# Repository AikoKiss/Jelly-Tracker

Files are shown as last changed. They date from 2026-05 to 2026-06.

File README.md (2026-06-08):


# Puchi Tracker
A smol-slime style tracker, with only the top-end parts, double-sided, NRF54L10 with ICM45686+QMC6309. Battery life is to be tested.

Thank you to Crylog for being an Absolute chad and unit of a PCB designer.
+ Mumo Tracker for the nice footprints and 3D files, making it easier to design the PCB.
+ Thank you, the slime community, for bullying all the bugs out of my design.
+ Special thanks to Meia for taking the time to help me squash all my stupid decisions and bugs.

## License

This project is source-available for personal and
educational use only.

Commercial use, manufacturing, resale, or distribution
For-profit is prohibited without written permission
from Limeneer Labs.

See the [LICENSE](LICENSE) file for full details.

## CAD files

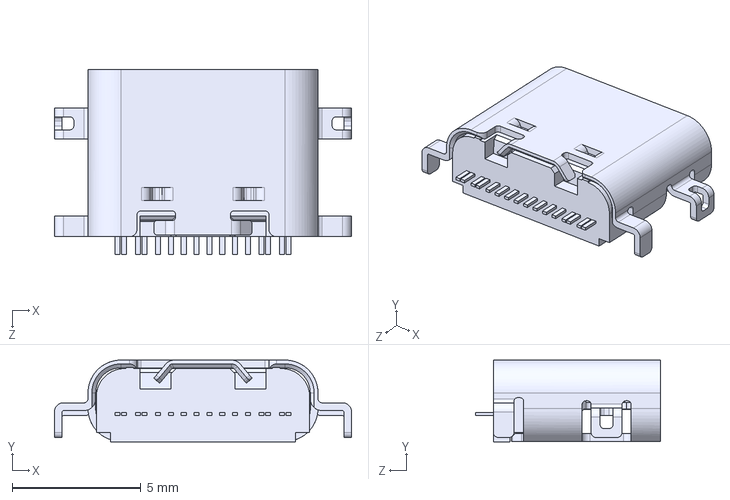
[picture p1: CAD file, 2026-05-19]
PuchiTrackerV6/GSB1C4621DS1HR/GSB1C4621DS1HR.step
11.5 x 3.18 x 7.20 mm

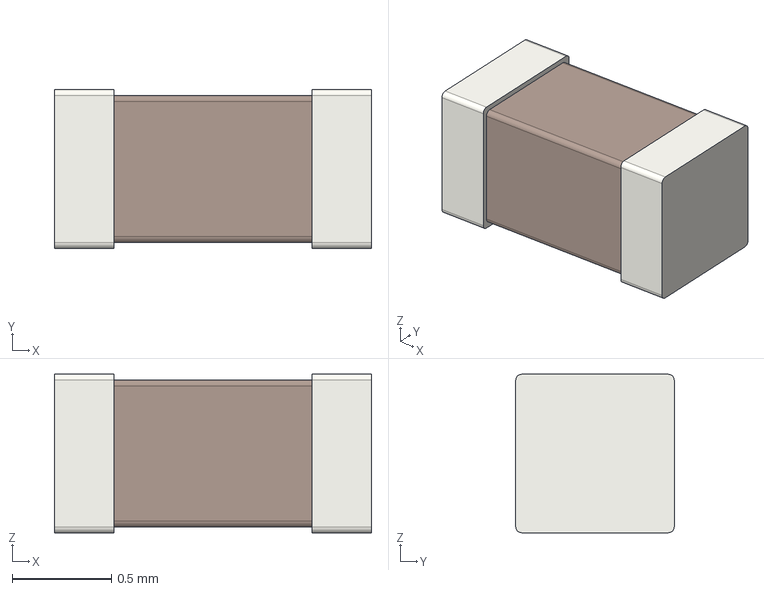
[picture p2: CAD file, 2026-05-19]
PuchiTrackerV6/Mumo Data/Mumo Models/C_0603_1608Metric.step
1.60 x 0.8 x 0.8 mm

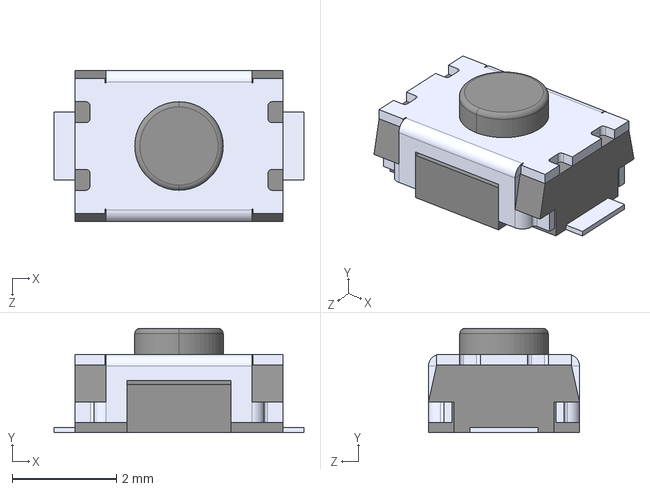
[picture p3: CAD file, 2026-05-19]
PuchiTrackerV6/TS-1088-AR02016/TS-1088-AR02016.step
4.80 x 2.00 x 2.90 mm

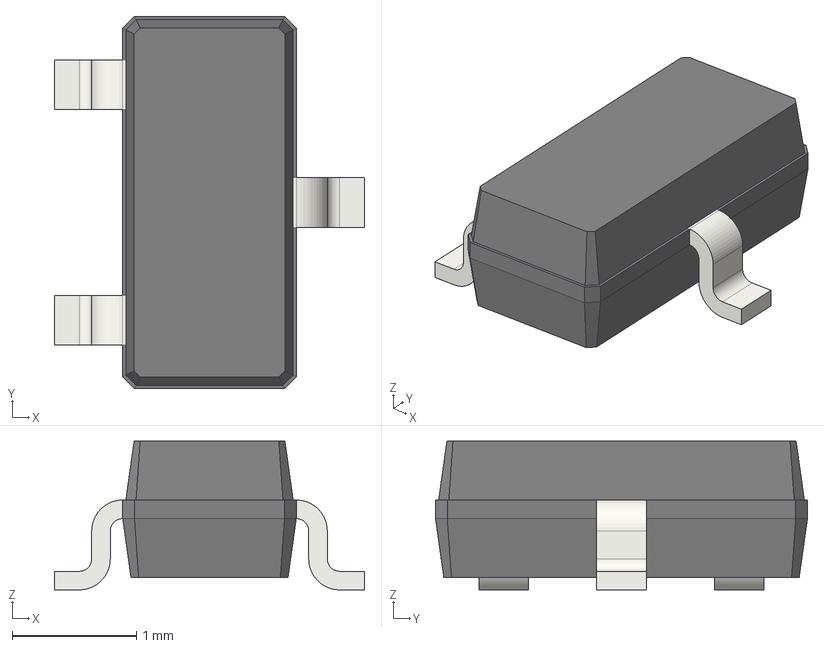
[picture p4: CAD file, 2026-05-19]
PuchiTrackerV6/Mumo Data/Mumo Models/SOT-23.step
2.50 x 3.00 x 1.20 mm

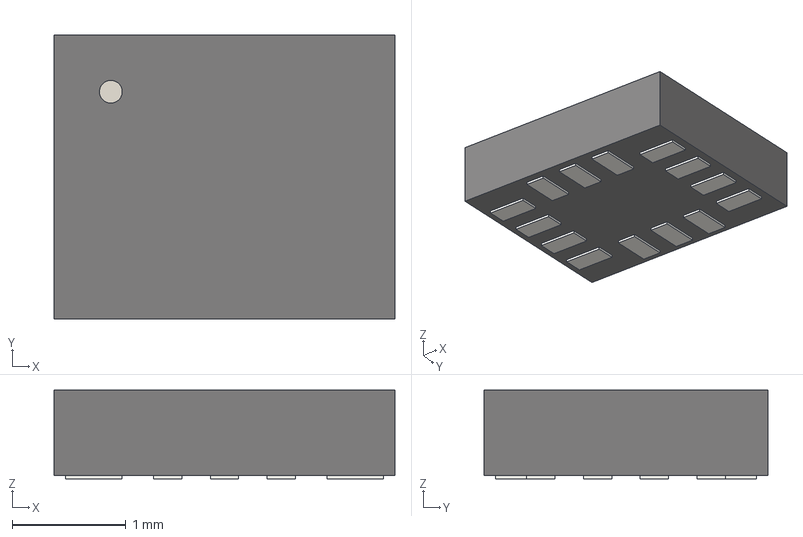
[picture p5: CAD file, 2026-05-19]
PuchiTrackerV6/Mumo Data/Mumo Models/Bosch_LGA-14_3x2.5mm_P0.5mm.step
3.00 x 2.50 x 0.78 mm

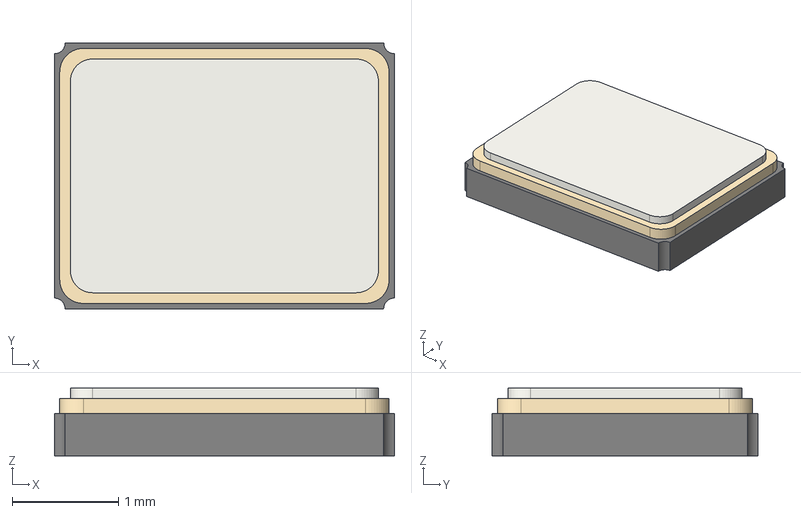
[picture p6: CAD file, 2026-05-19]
PuchiTrackerV6/Mumo Data/Mumo Models/Crystal_SMD_3225-4Pin_3.2x2.5mm.step
3.20 x 2.50 x 0.64 mm

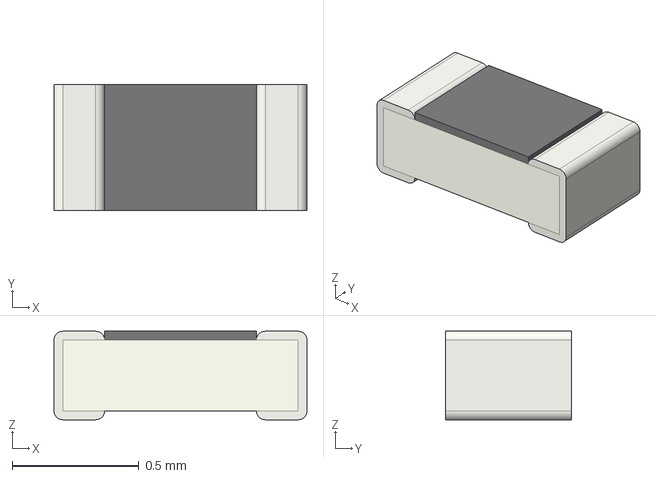
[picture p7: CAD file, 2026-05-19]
PuchiTrackerV6/Mumo Data/Mumo Models/R_0402_1005Metric.step
1.00 x 0.5 x 0.35 mm

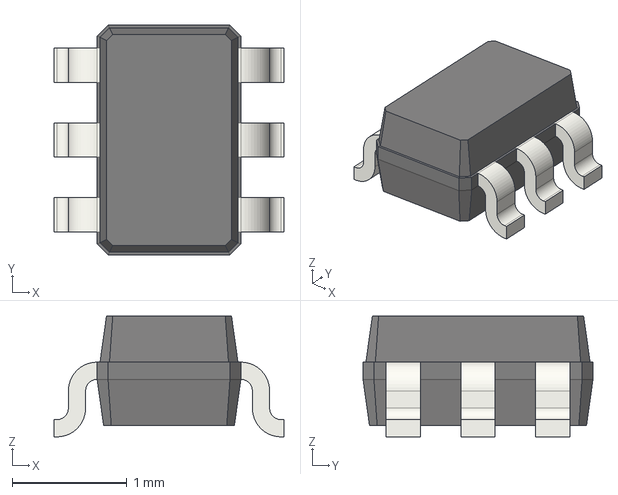
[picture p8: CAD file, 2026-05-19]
PuchiTrackerV6/Mumo Data/Mumo Models/SOT-363_SC-70-6.step
2.00 x 2.00 x 1.05 mm

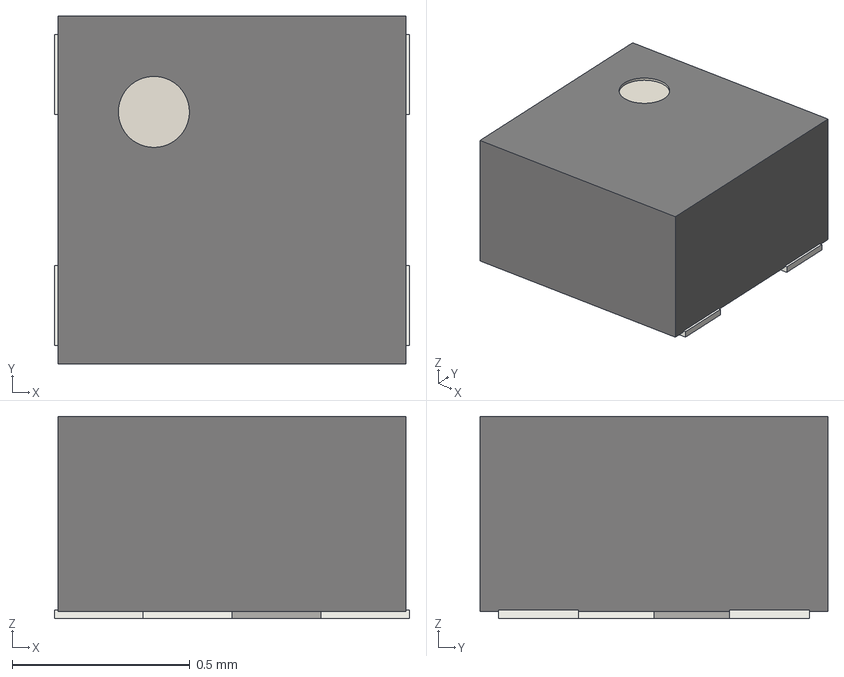
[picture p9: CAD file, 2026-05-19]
PuchiTrackerV6/Mumo Data/Mumo Models/UDFN-4-1EP_1x1mm_P0.65mm_EP0.48x0.48mm.step
1.00 x 0.98 x 0.57 mm

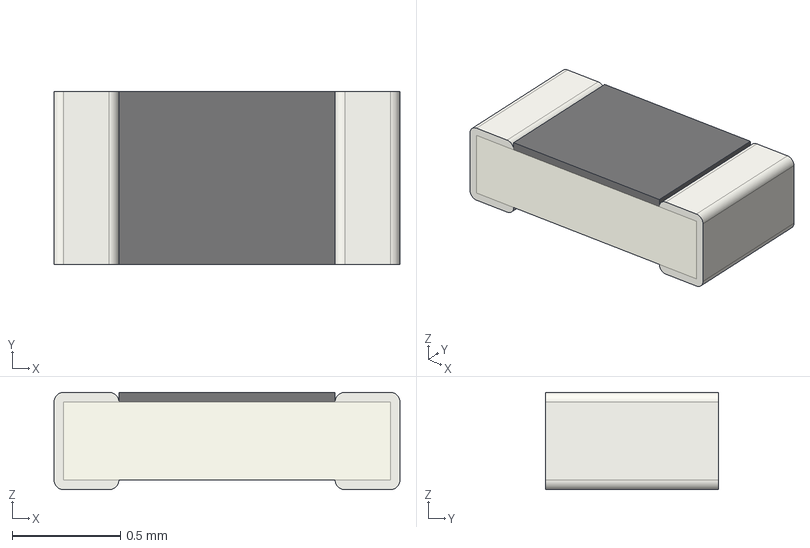
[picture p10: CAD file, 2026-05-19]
PuchiTrackerV6/Mumo Data/Mumo Models/R_0603_1608Metric.step
1.60 x 0.8 x 0.45 mm

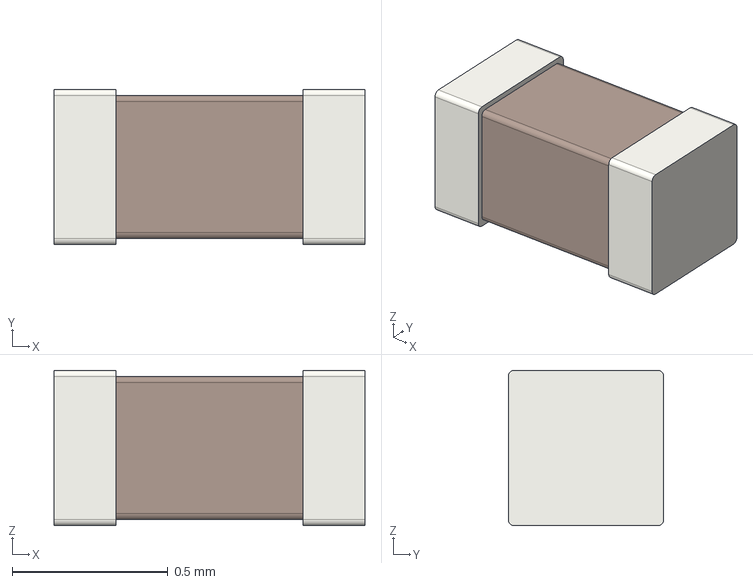
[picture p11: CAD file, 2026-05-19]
PuchiTrackerV6/Mumo Data/Mumo Models/C_0402_1005Metric.step
1.00 x 0.5 x 0.5 mm

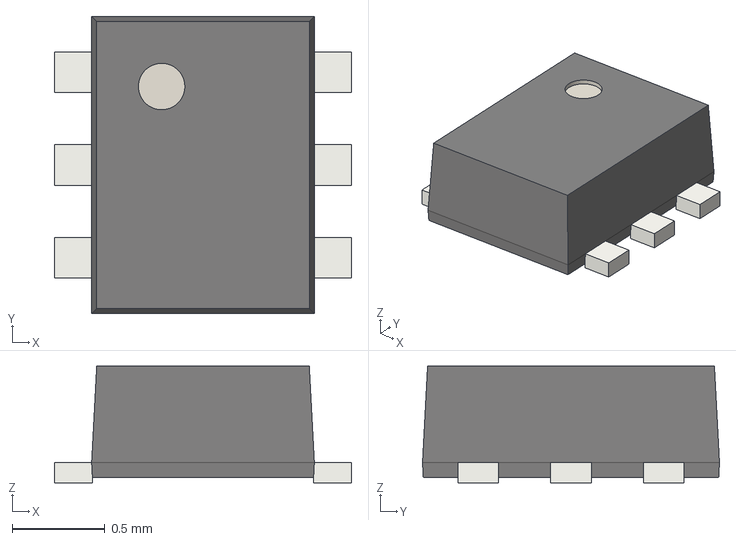
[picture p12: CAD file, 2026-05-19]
PuchiTrackerV6/Mumo Data/Mumo Models/SOT-563.step
1.60 x 1.60 x 0.63 mm

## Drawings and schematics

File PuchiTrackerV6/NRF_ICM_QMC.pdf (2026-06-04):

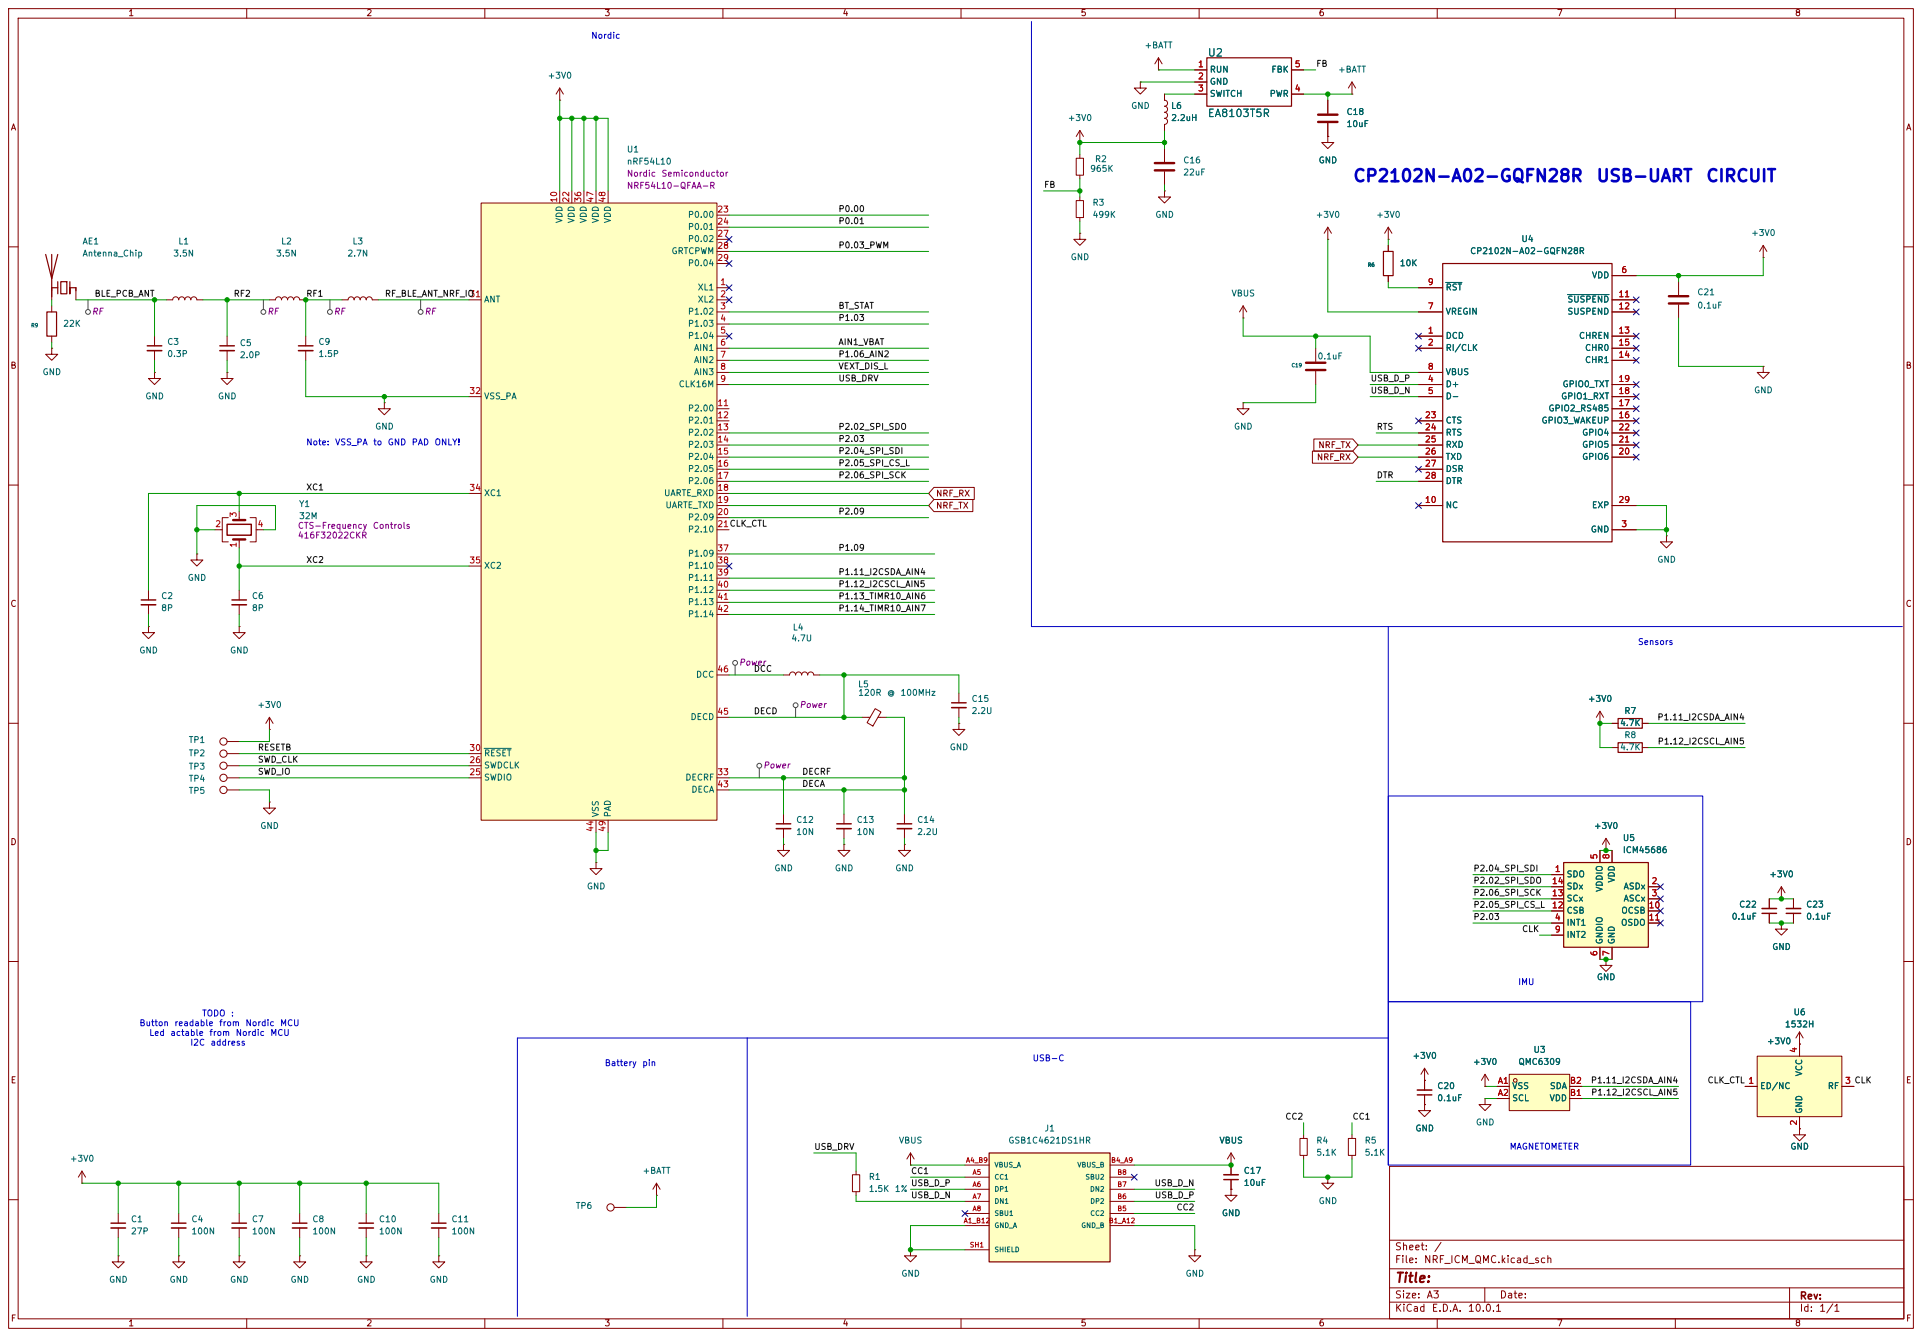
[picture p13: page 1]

IMU | ICM45686 GND +3V0 R5

TODO : Button readable from Nordic MCU

Led actable from Nordic MCU

GND

Size: A3 | Rev: | F Date:
KiCad E.D.A. 10.0.1 | Id: 1/1

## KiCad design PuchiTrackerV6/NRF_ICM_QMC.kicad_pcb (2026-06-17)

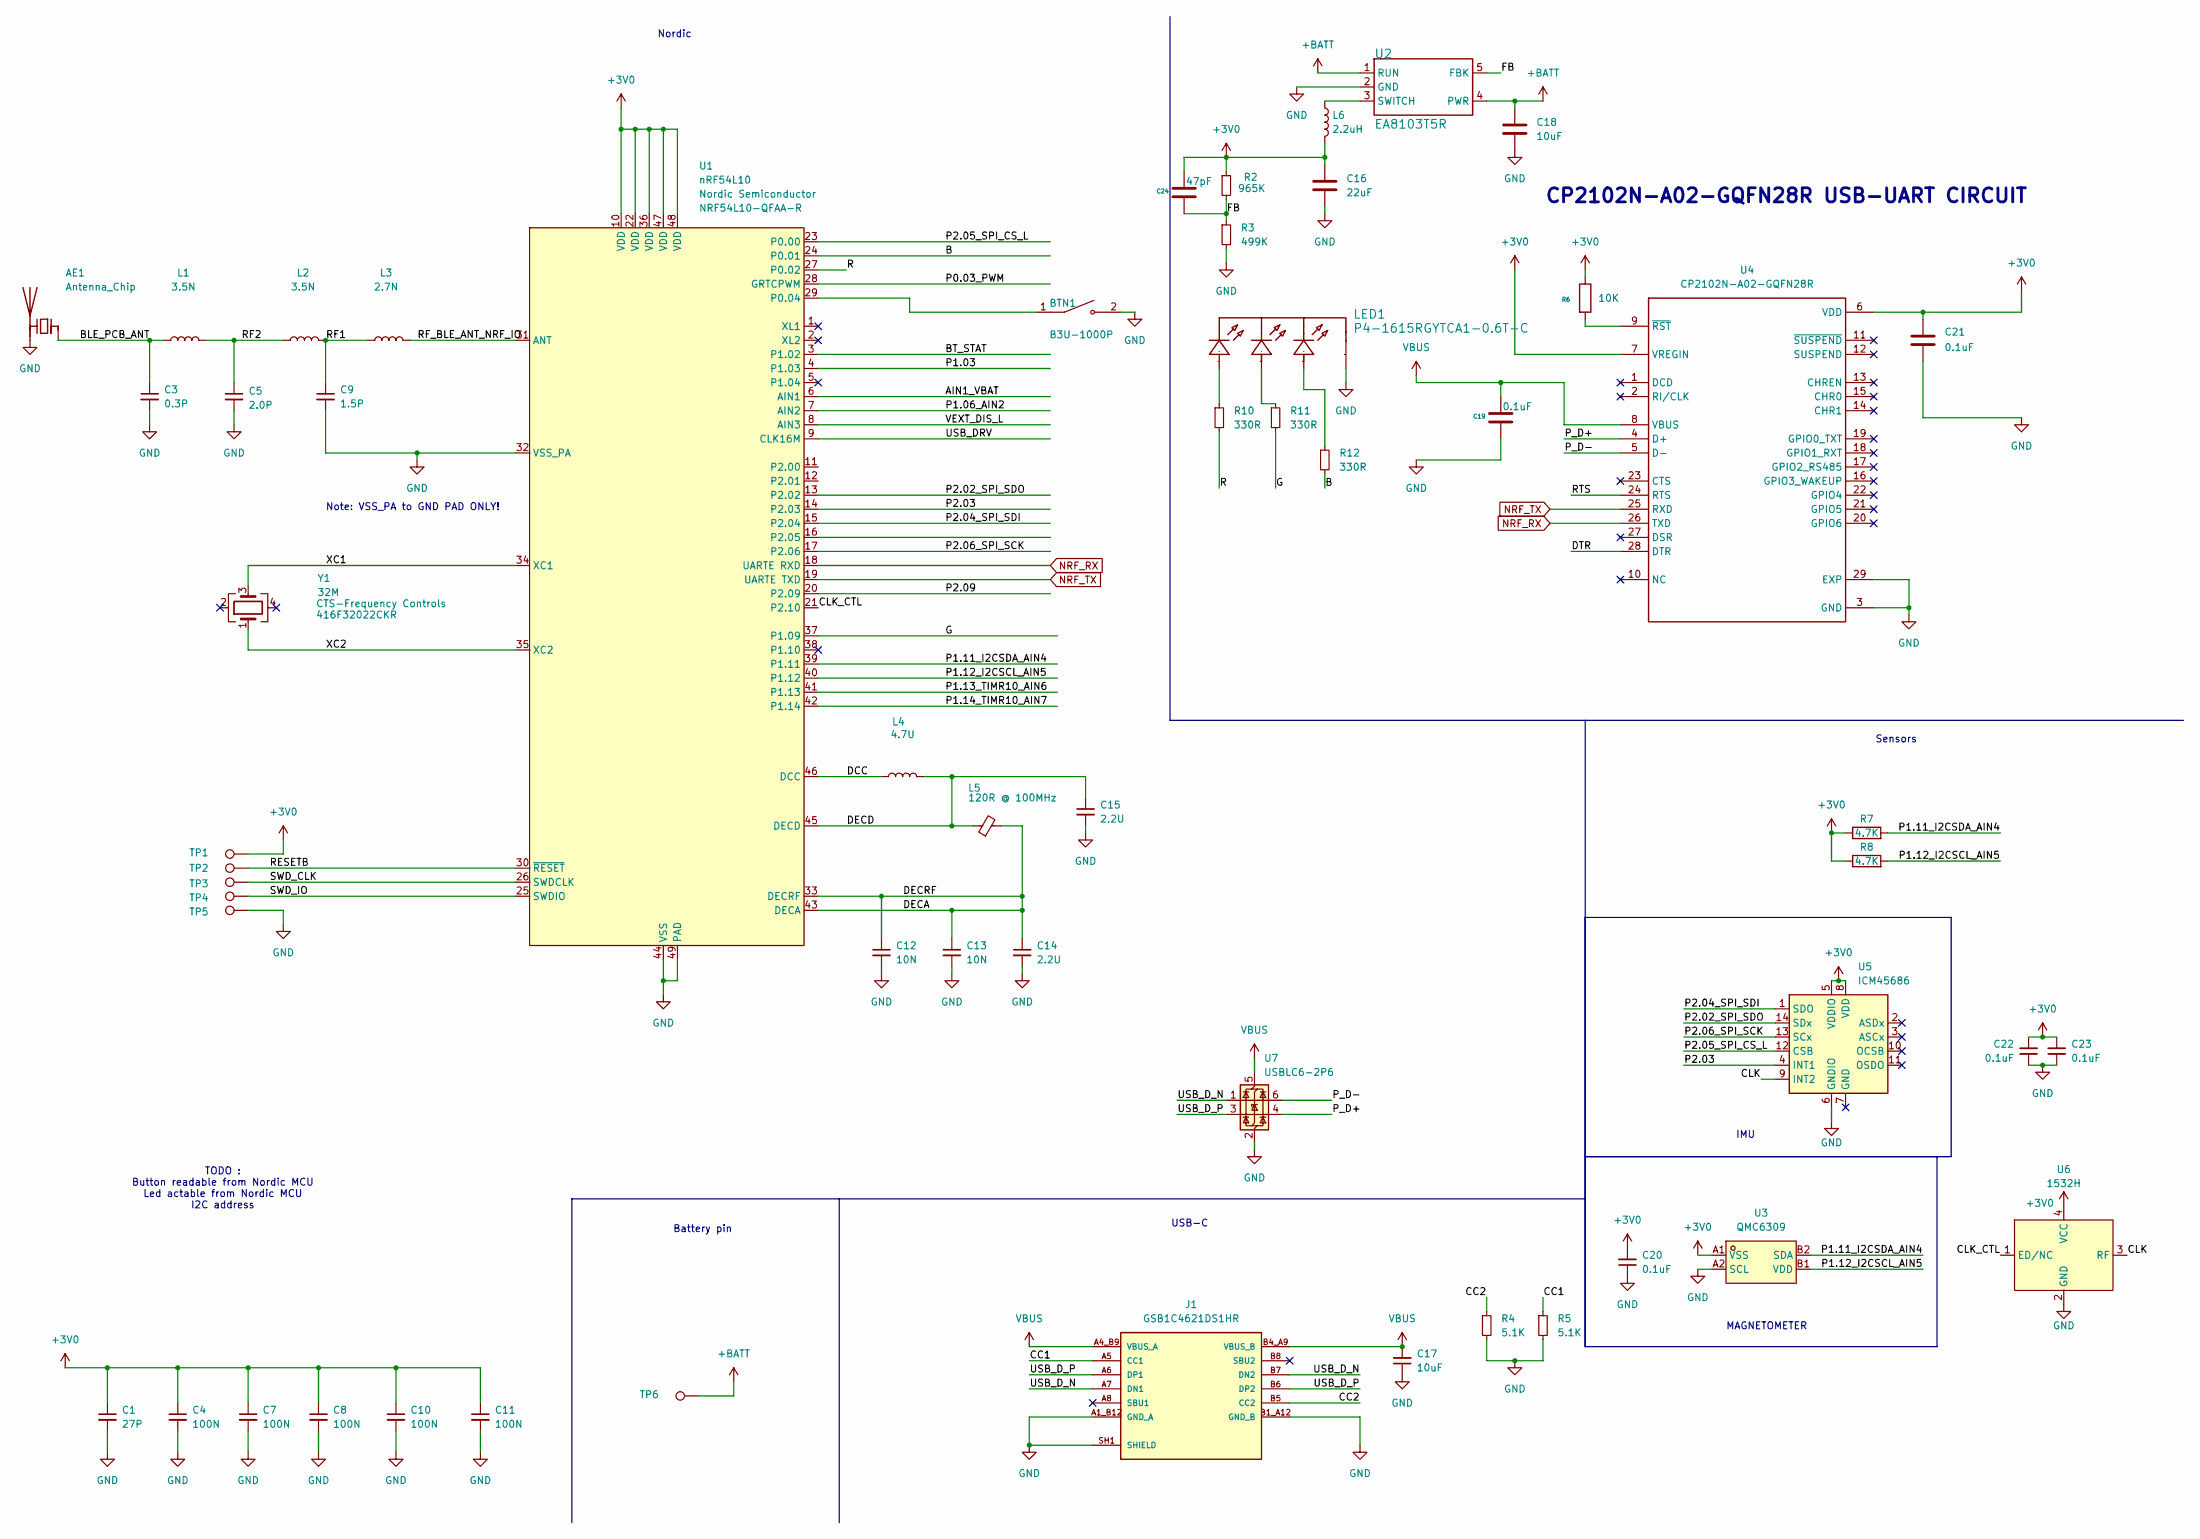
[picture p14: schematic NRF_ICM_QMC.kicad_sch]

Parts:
AE1: Antenna_Chip; MFG_PN 2450AT18A0100001E
BTN1: B3U-1000P; SW_SPST_B3U-1000P
C1: 27P; C_0402_1005Metric
C3: 0.3P; C_0402_1005Metric; MFG_PN GJM1555C1HR30WB01D
C4, C7, C8, C10, C11: 100N; C_0402_1005Metric
C5: 2.0P; C_0402_1005Metric; MFG_PN GJM0335C1E2R0WB01
C9: 1.5P; C_0402_1005Metric; MFG_PN GJM0335C1E1R5WB01
C12, C13: 10N; C_0402_1005Metric
C14, C15: 2.2U; C_0402_1005Metric
C16: 22uF; C_0402_1005Metric
C17, C18: 10uF; C_0402_1005Metric
C19, C20, C21, C22, C23: 0.1uF; C_0402_1005Metric
C24: 47pF; C_0402_1005Metric
J1: GSB1C4621DS1HR; AMPHENOL_GSB1C4621DS1HR; PARTREV AX1
L1, L2: 3.5N; L_0201_0603Metric; MFG_PN LQP03HQ3N5B02
L3: 2.7N; L_0201_0603Metric; MFG_PN LQP03HQ2N7B02
L4: 4.7U; L_0402_1005Metric; MFG_PN PLEA67BCA4R7M-1PT00
L5: 120R @ 100MHz; L_0201_0603Metric; MFG_PN BLM03AG121SN1D
L6: 2.2uH; L_1210_3225Metric
LED1: P4-1615RGYTCA1-0.6T-C; RGB; Manufacturer Part P4-1615RGYTCA1-0.6T-C; LCSC Part Name RGY三色
R2: 965K; R_0201_0603Metric
R3: 499K; R_0201_0603Metric
R4, R5: 5.1K; R_0201_0603Metric
R6: 10K; C_0402_1005Metric
R7, R8: 4.7K; R_0402_1005Metric
R10, R11, R12: 330R; R_0201_0603Metric
TP1, TP2, TP3, TP4, TP5, TP6: TestPoint; TestPoint_Pad_D1.0mm
U1: nRF54L10; QFN-48-1EP_6x6mm_P0.4mm_EP4.6x4.6mm; MFG_PN NRF54L10-QFAA-R
U2: EA8103T5R; Manufacturer Part EA8103T5R; LCSC Part Name 降压型 1.2A 2.6V~6V
U3: QMC6309; X1-WLB0808-4_L0.8-W0.8-P0.40-TL; MPN QMC6309; LCSC Part C5439871
U4: CP2102N-A02-GQFN28R; QFN-28-1EP_5x5mm_P0.5mm_EP3.1x3.1mm; PARTREV 1.5
U5: ICM45686; IMU (1)
U6: 1532H; CLK
U7: USBLC6-2P6; SOT-666
Y1: 32M; Oscillator_SMD_Abracon_ASCO-4Pin_1.6x1.2mm; MFG_PN 416F32022CKR

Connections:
+3V0: C1.1, C4.1, C7.1, C8.1, C10.1, C11.1, C16.1, C20.2, C21.1, C22.2, C23.2, C24.1, L6.2, R2.1, R6.1, R7.1, R8.1, TP1.1 (1_1), U1.10 (VDD), U1.22 (VDD), U1.36 (VDD), U1.47 (VDD), U1.48 (VDD), U3.A1 (VSS), U4.6 (VDD), U4.7 (VREGIN), U5.5 (VDDIO), U5.8 (VDD), U6.4 (VCC)
+BATT: C18.1, TP6.1 (1_1), U2.1 (RUN), U2.4 (PWR)
/AIN1_VBAT: U1.6 (AIN1)
/B: R12.2, U1.24 (P0.01)
/BLE_PCB_ANT: AE1.1 (FEED), C3.1, L1.1
/BT_STAT: U1.3 (P1.02)
/CC1: J1.A5 (CC1), R5.1
/CC2: J1.B5 (CC2), R4.1
/CLK: U5.9 (INT2), U6.3 (RF)
/CLK_CTL: U1.21 (P2.10), U6.1 (ED/NC)
/DCC: L4.1, U1.46 (DCC)
/DECA: C12.1, C13.1, C14.1, L5.2, U1.33 (DECRF), U1.43 (DECA)
/DECD: C15.1, L4.2, L5.1, U1.45 (DECD)
/DTR: U4.28 (DTR)
/FB: C24.2, R2.2, R3.1, U2.5 (FBK)
/G: R11.2, U1.37 (P1.09)
/P0.03_PWM: U1.28 (GRTCPWM)
/P1.03: U1.4 (P1.03)
/P1.06_AIN2: U1.7 (AIN2)
/P1.11_I2CSDA_AIN4: R7.2, U1.39 (P1.11), U3.B2 (SDA)
/P1.12_I2CSCL_AIN5: R8.2, U1.40 (P1.12), U3.B1 (VDD)
/P1.13_TIMR10_AIN6: U1.41 (P1.13)
/P1.14_TIMR10_AIN7: U1.42 (P1.14)
/P2.02_SPI_SDO: U1.13 (P2.02), U5.14 (SDx)
/P2.03: U1.14 (P2.03), U5.4 (INT1)
/P2.04_SPI_SDI: U1.15 (P2.04), U5.1 (SDO)
/P2.05_SPI_CS_L: U1.23 (P0.00), U5.12 (CSB)
/P2.06_SPI_SCK: U1.17 (P2.06), U5.13 (SCx)
/P2.09: U1.20 (P2.09)
/P_D+: U4.4 (D+), U7.4 (I/O2)
/P_D-: U4.5 (D-), U7.6 (I/O1)
/R: R10.2, U1.27 (P0.02)
/RESETB: TP2.1 (1_1), U1.30 (~RESET)
/RF1: C9.1, L2.2, L3.1
/RF2: C5.1, L1.2, L2.1
/RF_BLE_ANT_NRF_IO: L3.2, U1.31 (ANT)
/RTS: U4.24 (RTS)
/SWD_CLK: TP3.1 (1_1), U1.26 (SWDCLK)
/SWD_IO: TP4.1 (1_1), U1.25 (SWDIO)
/USB_DRV: U1.9 (CLK16M)
/USB_D_N: J1.A7 (DN1), J1.B7 (DN2), U7.1 (I/O1)
/USB_D_P: J1.A6 (DP1), J1.B6 (DP2), U7.3 (I/O2)
/VEXT_DIS_L: U1.8 (AIN3)
/XC1: U1.34 (XC1), Y1.3
/XC2: U1.35 (XC2), Y1.1
GND: AE1.2 (PCB_Trace), BTN1.2, C1.2, C3.2, C4.2, C5.2, C7.2, C8.2, C9.2, C10.2, C11.2, C12.2, C13.2, C14.2, C15.2, C16.2, C17.1, C18.2, C19.2, C20.1, C21.2, C22.1, C23.1, J1.A1_B12 (GND_A), J1.B1_A12 (GND_B), J1.SH1 (SHIELD), J1.SH2 (SHIELD), J1.SH3 (SHIELD), J1.SH4 (SHIELD), LED1.1 (V), R3.2, R4.2, R5.2, TP5.1 (1_1), U1.32 (VSS_PA), U1.44 (VSS), U1.49 (PAD), U2.2 (GND), U3.A2 (SCL), U4.3 (GND), U4.29 (EXP), U5.6 (GNDIO), U6.2 (GND), U7.2 (GND)
NRF_RX: U1.18 (UARTE RXD), U4.26 (TXD)
NRF_TX: U1.19 (UARTE TXD), U4.25 (RXD)
unnamed: LED1.4 (B), R12.1
unnamed: LED1.3 (G), R11.1
unnamed: LED1.2 (R), R10.1
unnamed: BTN1.1, U1.29 (P0.04)
unnamed: L6.1, U2.3 (SWITCH)
unnamed: R6.2, U4.9 (~RST)
VBUS: C17.2, C19.1, J1.A4_B9 (VBUS_A), J1.B4_A9 (VBUS_B), U4.8 (VBUS), U7.5 (VBUS)

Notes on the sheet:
Nordic
USB-C
MAGNETOMETER
TODO : Button readable from Nordic MCU Led actable from Nordic MCU I2C address
Note: VSS_PA to GND PAD ONLY!
IMU
Sensors
Battery pin
CP2102N-A02-GQFN28R USB-UART CIRCUIT

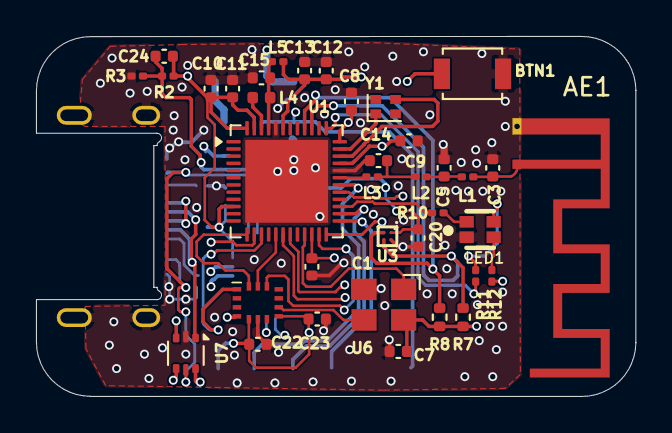
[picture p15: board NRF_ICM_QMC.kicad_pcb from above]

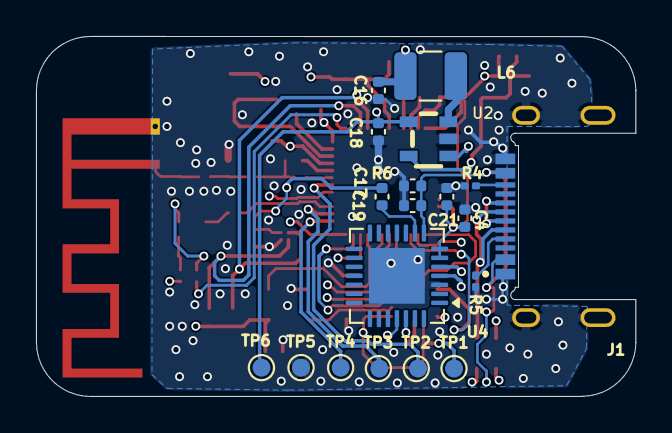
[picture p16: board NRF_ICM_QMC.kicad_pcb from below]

Board: 4 copper layers, 33.3 x 20.0 mm, 56 parts (19 on the bottom side), 43 nets.

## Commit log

2026-05-19 First Upload
    [Bosch_LGA-14_3x2.5mm_P0.5mm.step, C_0402_1005Metric.step, C_0603_1608Metric.step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]
2026-05-19 Update README with acknowledgments
    Added acknowledgments for PCB design contributions.
2026-06-04 V2
    Fixed EVERYTHING, i Think
    [Bosch_LGA-14_3x2.5mm_P0.5mm.step, C_0402_1005Metric.step, C_0603_1608Metric.step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]
2026-06-06 V3
    Updated, with fixes
    [Bosch_LGA-14_3x2.5mm_P0.5mm.step, C_0402_1005Metric.step, C_0603_1608Metric.step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]
2026-06-06 Delete PuchiTrackerV2 directory
    Old Ver delete
    [Bosch_LGA-14_3x2.5mm_P0.5mm.step, C_0402_1005Metric.step, C_0603_1608Metric.step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]
2026-06-07 Delete PuchiTrackerV3 directory
    Update to V4
    [Bosch_LGA-14_3x2.5mm_P0.5mm.step, C_0402_1005Metric.step, C_0603_1608Metric.step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]
2026-06-07 V4 Puchi Tracker
    Fixed Atenna, DC/DC improvement, moved cs pin to p0.00
    [Bosch_LGA-14_3x2.5mm_P0.5mm.step, C_0402_1005Metric.step, C_0603_1608Metric.step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]
2026-06-08 PuchiV5
    Fixed More stuff
    [Bosch_LGA-14_3x2.5mm_P0.5mm.step, C_0402_1005Metric.step, C_0603_1608Metric.step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]
2026-06-14 PuchiTrackerV6
    V6 Update, Changed Layer stack
    [Bosch_LGA-14_3x2.5mm_P0.5mm.step, C_0402_1005Metric.step, C_0603_1608Metric.step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]
2026-06-17 PuchiTrackerV6
    Fixed and ready to go
    [Bosch_LGA-14_3x2.5mm_P0.5mm.step, C_0402_1005Metric.step, C_0603_1608Metric.step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]

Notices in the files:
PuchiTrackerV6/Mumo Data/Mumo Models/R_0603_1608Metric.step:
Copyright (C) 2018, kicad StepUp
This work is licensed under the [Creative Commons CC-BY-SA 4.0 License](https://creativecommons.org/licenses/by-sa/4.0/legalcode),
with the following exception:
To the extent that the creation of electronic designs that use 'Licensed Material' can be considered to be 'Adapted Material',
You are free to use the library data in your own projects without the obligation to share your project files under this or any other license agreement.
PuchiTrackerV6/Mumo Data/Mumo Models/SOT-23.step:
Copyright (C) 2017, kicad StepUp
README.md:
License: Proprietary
